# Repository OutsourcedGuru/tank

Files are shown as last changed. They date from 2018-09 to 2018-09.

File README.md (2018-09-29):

# tank
An automomously/manually driven tank with Arduino (C) and Raspberry Pi Zero W (Python/Node.js) with additional remote-control Raspberry Pi Zero W

## Overview
This project involves assembly of the tank kit itself, soldering to add the 3-pin header to the Raspberry Pi Zero W circuit board, 3D printing of the housing for the Pi Zero and a reasonable understanding of both C programming in the Arduino software as well as Python and NodeJS (JavaScript) programming on the Raspberry.

The tank's stepper motors are driven by the Arduino + 6612 shield combination. There appears to be plenty of examples to get this going.

The driving logic, however, are on the Raspberry Pi Zero W since it has wi-fi, a full operating system, easy access to a camera and streaming as well as robust platforms such as NodeJS.

A serial link and interface connects the two separate systems which all sit atop the tank itself. Since the communication is one-way, I've decided not to use a logic-level converter from the Raspi's 3.3V to the Arduino's expected 5V; it works as long as the baudrate is throttled at 4800.

### Phase 1
[x] In the first phase of the project, a simple Python script running on the Pi will send commands over the serial interface to the Arduino for steering.

### Phase 2
[x] In the second phase, a NodeJS web interface on the Pi will allow both the webcam stream to be viewed plus to control the tank, presumably from an iPhone.

### Phase 3
[x] In the third phase, individual frames from the camera will be analyzed to allow a NodeJS program to automamously steer the tank around a course.

## Parts

* [OSEPP Tank Mechanical Kit](https://www.osepp.com/robotic-kits/4-tank-mechanical-kit)
* [OSEPP Mega 2560 R3 Plus](https://www.osepp.com/electronic-modules/microcontroller-boards/101-osepp-mega-2560-r3-plus)
* [OSEPP Motor Shield 6612](https://www.osepp.com/electronic-modules/shields/120-motor-shield-6612)
* [Raspberry Pi Zero W](https://www.adafruit.com/product/3400)
* [Raspberry Pi Camera Board](https://www.adafruit.com/product/3099)
* [Ribbon Cable for Pi Zero](https://www.adafruit.com/product/3157)
* 4GB or larger microSD for the Raspberry Pi Zero W
* M-F 6" connection wiring
* Break-away jumpers (3 pins) for the Raspberry Pi Zero W
* Extra aluminim bolts, standoffs of different sizes

tank_01___1_-759-800-600-80

meg_03__1_-648-800-600-80

tbshd_01__1_-772-800-600-80

raspberry-3400-00

camera-3099-04

cable-3157-02

## Schematic
This is a limited version of the schematic in that Fritzing doesn't yet have the OSEPP 6612 Motor Shield board definition. The shield sits on top of the OSEPP Mega 2560 R3 Plus board itself, taking in the 9V DC power supply and providing it back to each of two servo motors which drive the tracks.

schematic

|Description|Version|Author|Last Update|
|:---|:---|:---|:---|
|tank|v1.1.6|OutsourcedGuru|September 20, 2018|

|Donate||Cryptocurrency|
|:-----:|---|:---:|
| eth-receive || btc-receive |
|Ethereum||Bitcoin|

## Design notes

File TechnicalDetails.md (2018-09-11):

# Technical Details
The following is a bit of a diary involving the design decisions and research that went into this project.

Examples [1](#1)

```
/*
  Software serial multple serial test

 Receives from the hardware serial, sends to software serial.
 Receives from software serial, sends to hardware serial.

 The circuit:
 * RX is digital pin 10 (connect to TX of other device)
 * TX is digital pin 11 (connect to RX of other device)

 Note:
 Not all pins on the Mega and Mega 2560 support change interrupts,
 so only the following can be used for RX:
 10, 11, 12, 13, 50, 51, 52, 53, 62, 63, 64, 65, 66, 67, 68, 69

 Not all pins on the Leonardo and Micro support change interrupts,
 so only the following can be used for RX:
 8, 9, 10, 11, 14 (MISO), 15 (SCK), 16 (MOSI).

 created back in the mists of time
 modified 25 May 2012
 by Tom Igoe
 based on Mikal Hart's example

 This example code is in the public domain.

 */
#include <SoftwareSerial.h>

SoftwareSerial mySerial(10, 11); // RX, TX

void setup() {
  // Open serial communications and wait for port to open:
  Serial.begin(57600);
  while (!Serial) {
    ; // wait for serial port to connect. Needed for native USB port only
  }

  Serial.println("Goodnight moon!");

  // set the data rate for the SoftwareSerial port
  mySerial.begin(4800);
  mySerial.println("Hello, world?");
}

void loop() { // run over and over
  if (mySerial.available()) {
    Serial.write(mySerial.read());
  }
  if (Serial.available()) {
    mySerial.write(Serial.read());
  }
}
```

## SoftWareSerial Library

> "Not all pins on the Mega and Mega 2560 support change interrupts, so only the following can be used for RX: 10, 11, 12, 13, 14, 15, 50, 51, 52, 53, A8 (62), A9 (63), A10 (64), A11 (65), A12 (66), A13 (67), A14 (68), A15 (69)." [2](#2)

This will be the library I'll use on the Arduino side of things.

* SoftwareSerial() [4](#4)
* begin(baudrate) [5](#5)
* listen() [6](#6)
* read() [7](#7)
* parseInt() [8](#8)
* ReadASCIIString example [9](#9)

```
SoftwareSerial mySerial(10,11);

void setup()
{
  mySerial.begin(9600);
}

void loop()
{
  char c = mySerial.read();
}
```

```
#include <SoftwareSerial.h>

#define rxPin 10
#define txPin 11

// set up a new serial port
SoftwareSerial mySerial =  SoftwareSerial(rxPin, txPin);

void setup()  {
  // define pin modes for tx, rx:
  pinMode(rxPin, INPUT);
  pinMode(txPin, OUTPUT);
  // set the data rate for the SoftwareSerial port
  mySerial.begin(9600);
}
```

## Two-Serial Ports at Once on Arduino
```
/*
  Software serial multple serial test

 Receives from the two software serial ports,
 sends to the hardware serial port.

 In order to listen on a software port, you call port.listen().
 When using two software serial ports, you have to switch ports
 by listen()ing on each one in turn. Pick a logical time to switch
 ports, like the end of an expected transmission, or when the
 buffer is empty. This example switches ports when there is nothing
 more to read from a port

 The circuit:
 Two devices which communicate serially are needed.
 * First serial device's TX attached to digital pin 10(RX), RX to pin 11(TX)
 * Second serial device's TX attached to digital pin 8(RX), RX to pin 9(TX)

 Note:
 Not all pins on the Mega and Mega 2560 support change interrupts,
 so only the following can be used for RX:
 10, 11, 12, 13, 50, 51, 52, 53, 62, 63, 64, 65, 66, 67, 68, 69

 Not all pins on the Leonardo support change interrupts,
 so only the following can be used for RX:
 8, 9, 10, 11, 14 (MISO), 15 (SCK), 16 (MOSI).

 created 18 Apr. 2011
 modified 19 March 2016
 by Tom Igoe
 based on Mikal Hart's twoPortRXExample

 This example code is in the public domain.

 */

#include <SoftwareSerial.h>
// software serial #1: RX = digital pin 10, TX = digital pin 11
SoftwareSerial portOne(10, 11);

// software serial #2: RX = digital pin 8, TX = digital pin 9
// on the Mega, use other pins instead, since 8 and 9 don't work on the Mega
SoftwareSerial portTwo(8, 9);

void setup() {
  // Open serial communications and wait for port to open:
  Serial.begin(9600);
  while (!Serial) {
    ; // wait for serial port to connect. Needed for native USB port only
  }

  // Start each software serial port
  portOne.begin(9600);
  portTwo.begin(9600);
}

void loop() {
  // By default, the last intialized port is listening.
  // when you want to listen on a port, explicitly select it:
  portOne.listen();
  Serial.println("Data from port one:");
  // while there is data coming in, read it
  // and send to the hardware serial port:
  while (portOne.available() > 0) {
    char inByte = portOne.read();
    Serial.write(inByte);
  }

  // blank line to separate data from the two ports:
  Serial.println();

  // Now listen on the second port
  portTwo.listen();
  // while there is data coming in, read it
  // and send to the hardware serial port:
  Serial.println("Data from port two:");
  while (portTwo.available() > 0) {
    char inByte = portTwo.read();
    Serial.write(inByte);
  }

  // blank line to separate data from the two ports:
  Serial.println();
}
```
Pins 2 and 4 are separate RX inputs; 3 and 5 are TX outputs. [3](#3)

# Raspberry Pi Zero W Setup
I assume here that the Raspberry Pi Zero W has gone through its initial paces of receiving a hostname, adjusting the timezone/localization settings and expanding the file system. I also assume that mjpg_streamer has been installed and the necessary changes for this to include plugging in the Pi cam.

1. Solder three-pin header to pins 4, 6, 8 (5V, Gnd, BCM 14 Tx)
2. Connect red to 4, black to 6 and blue to 8. On the Arduino end, red to 5V and black to Gnd in the POWER section and blue to 10 on the opposite side
3. `sudo apt-get update`
4. `sudo apt-get install python-pip`
5. `pip install pyserial` # Enough preparation for Phase 1
6. `sudo apt-get install git`
7. `mkdir ~/tmp && cd ~/tmp`
8. `wget https://nodejs.org/dist/v8.11.4/node-v8.11.4-linux-armv6l.tar.xz`
9. `tar -xvf *.xz`
10. `cd node*l`
11. `sudo cp -R * /usr/local/`
12. `node --version`
13. `cd ~/sites && rm -R ~/tmp` # Node.js and npm are now installed
14. `sudo npm install -g express-generator`
15. `express --ejs tank && cd tank && npm install`
16. `DEBUG=tank:* npm start`
17. `npm install --save raspi` # Adding serial support to web interface
18. `npm install --save raspi-serial`

## Lane-recognition transforms

The series of steps to accomplish the goal for this project are as follows: [10](#10)

1. Compute the camera calibration matrix and distortion coefficients.
2. Apply a distortion correction to raw images.
3. Use color transforms, gradients, etc., to create a thresholded binary image.
4. Apply a perspective transform to generate a “bird’s-eye view” of the image.
5. Detect lane pixels and fit to find the lane boundary.
6. Determine the curvature of the lane and vehicle position with respect to center.
7. Warp the detected lane boundaries back onto the original image and display numerical estimation of lane curvature and vehicle position.

## Bibliography

#### 1. [Arduino Serial Examples](https://www.arduino.cc/en/Tutorial/SoftwareSerialExample)

#### 2. [Arduino SoftwareSerial](https://www.arduino.cc/en/Reference/SoftwareSerial)

#### 3. [Arduino Two-Port Receive](https://www.arduino.cc/en/Tutorial/TwoPortReceive)

#### 4. [SoftwareSerial constructor](https://www.arduino.cc/en/Reference/SoftwareSerialConstructor)

#### 5. [begin(baudrate)](https://www.arduino.cc/en/Reference/SoftwareSerialBegin)

#### 6. [listen()](https://www.arduino.cc/en/Reference/SoftwareSerialListen)

#### 7. [read()](https://www.arduino.cc/en/Reference/SoftwareSerialRead)

#### 8. [parseInt()](https://www.arduino.cc/en/Reference/ParseInt)

#### 9. [ReadASCIIString example](https://www.arduino.cc/en/Tutorial/ReadASCIIString)

#### 10. [Advanced Land Detection for Autonomous Vehicles](https://towardsdatascience.com/advanced-lane-detection-for-autonomous-vehicles-using-computer-vision-techniques-f229e4245e41)

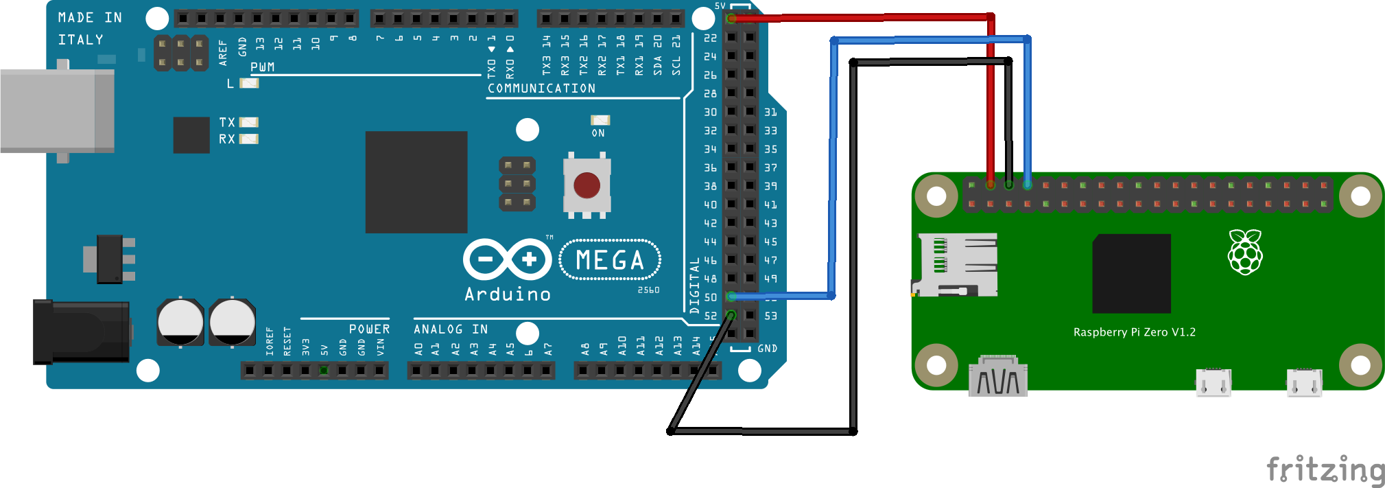
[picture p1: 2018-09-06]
Schematic.png

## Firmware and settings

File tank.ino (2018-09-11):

/*
 * OBJECT AVOIDANCE WITH SERVO
 * 
 * Robot will avoid objects in front.
 * Ultrasonic sensor scans for the best route to take
 * Robot can't detect objects at it's side, best to install 2 IR Detectors
 *
 * Best used on OSEPP Mechanical Kits.
 * TANK-01
 * TRITANK-01
 *
 * created 08 Nov 2016
 * by Sui Wei
 *
 */
 
#include "sensorsDRV.h"
#include <avr/wdt.h>
#include "TBMotor.h"
#include <Servo.h>
#include <SoftwareSerial.h>

//OseppTBMotor Motor1(12, 11);
//OseppTBMotor Motor2(8, 3);
OseppTBMotor Motor3(7, 6);
OseppTBMotor Motor4(4, 5);
#define leftMotor Motor3
#define rightMotor Motor4
int leftSpeed = 0;
int rightSpeed = 0;
SoftwareSerial portConsole(0, 1);
SoftwareSerial portRaspi(52, 14);


void setup()
{
  //Setup a watchdog
  //When the battery voltage is insufficient / program unexpected
  //Watchdog reset chip
  wdt_enable(WDTO_4S);
  // Setup both serial connections
  portConsole.begin(115200);
  portRaspi.begin(4800);
  portConsole.println("Starting serial...");
}

void loop()
{
//  const float threshold = 300;
  char strChar[2];
  strChar[0] = strChar[1] = '\0';

  //If in 4 seconds,The program is not coming back here.
  //Chip will reset
  wdt_reset();

  char *pstrCommand = "";
  int nLeft = 0, nRight = 0;
  while (portRaspi.available() > 0) {
    char inByte = portRaspi.read();
    if (inByte == '\n') {
      portConsole.print("\n");
      char strLeft[5] = "", strRight[5] = "";
      if (pstrCommand[0] == 'L') {
        char *pSpace = strstr(pstrCommand, " ");
        if (pSpace) {
          int nSpaceOffset = pSpace - pstrCommand;
          int nLengthLeftNumber = pSpace - pstrCommand - 1;
          int nLengthRightNumber = strlen(pstrCommand) - nLengthLeftNumber - 3;
          // Copy the left number
          strncpy(strLeft, pstrCommand + 1, nLengthLeftNumber);
          strLeft[nLengthLeftNumber] = '\0';
          // Copy the right number
          strncpy(strRight, pSpace + 2, nLengthRightNumber);
          strRight[nLengthRightNumber] = '\0';
          nLeft = atoi(strLeft);
          nRight = atoi(strRight);
          // Now set the motors
          leftSpeed = nLeft;
          rightSpeed = nRight;
          setMotors();
        }
      }
      // Empty out the line buffer
      pstrCommand[0] = '\0';
    } else {
      // Add one to the line buffer
      strChar[0] = inByte;
      pstrCommand = strcat(pstrCommand, strChar);
    }
  }
}

void setMotors()
{
  if (leftSpeed > 255)  leftSpeed = 255;  else if (leftSpeed < -255)  leftSpeed = -255;
  if (rightSpeed > 255) rightSpeed = 255; else if (rightSpeed < -255) rightSpeed = -255;
  leftMotor.SetSpeed(leftSpeed);
  rightMotor.SetSpeed(rightSpeed);
}

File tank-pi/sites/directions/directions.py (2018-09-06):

#!/usr/bin/python

import time
import serial

# BCM 14, BOARD 8 is the TX pin used on the Raspberry
ser = serial.Serial('/dev/serial0', 4800)

while True:
        ser.write('L50 R50\n')
        print 'L50 R50'
        time.sleep(5.0)

        ser.write('L0 R0\n')
        print 'L0 R0'
        time.sleep(5.0)

        ser.write('L100 R-100\n')
        print 'L100 R-100'
        time.sleep(5.0)

        ser.write('L0 R0\n')
        print 'L0 R0'
        time.sleep(5.0)

        ser.write('L-100 R100\n')
        print 'L-100 R100'
        time.sleep(5.0)

        ser.write('L-50 R50\n')
        print 'L-50 R50'
        time.sleep(5.0)

        ser.write('L0 R0\n')
        print 'L0 R0'
        time.sleep(10.0)

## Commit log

2018-09-06 v1.0.1 Initial push, Phase 1 completed
    [Schematic.fzz]
2018-09-16 v1.0.11 Better steering logic
2018-09-17 v1.1.4 More track data
2018-09-24 v1.1.9 Added Jimp protototypes and track data
